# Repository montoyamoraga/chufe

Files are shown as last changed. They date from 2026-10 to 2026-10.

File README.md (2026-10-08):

# chufe

## About

chufe is an open source hardware Eurorack power supply by [piruetas](https://piruetas.xyz). It takes 12 V DC from a barrel jack, with reverse polarity protection, and outputs ±12V (from a 20 W isolated DC-DC converter) and +5V (from an L7805 linear regulator) on a 16-pin Eurorack power header and a 4-pin Molex KK-396 connector, with an LED for each rail. It is designed to feed a power bus such as [chufebu](https://github.com/piruetasxyz/chufebu). The design is made in KiCad 10 with KiCad's standard libraries plus one third-party part, included in `terceros/`. Hardware is licensed under CERN-OHL-P-2.0 and documentation under CC-BY-SA-4.0 (see [LICENSE.md](./LICENSE.md)). Documentation, schematic, board render and bill of materials (in Spanish): <https://piruetas.xyz/chufe/>.

## Acerca de

Fuente de alimentación eurorack de [piruetas](https://piruetas.xyz), hecha en KiCad y publicada como hardware de código abierto.

Documentación, esquemático, placa y Bill of materials: <https://piruetas.xyz/chufe/>.

## Características

- Entrada de 12 V DC por jack, con protección contra polaridad inversa.
- Salidas de +12V y -12V desde un convertidor DC-DC aislado de 20 W (URA2412YMD-20WR3).
- Salida de +5V desde un regulador lineal L7805, alimentado desde +12V.
- Un header de alimentación Eurorack de 16 pines (2x08) y un conector Molex KK-396 de 4 pines: -12V, GND, +5V y +12V.
- 4 LEDs indicadores: entrada, -12V, +12V y +5V.
- Placa de 50 × 65 mm, 2 capas, con 4 agujeros de montaje M3.
- Hecha para alimentar un bus como [chufebu](https://github.com/piruetasxyz/chufebu).

## Pines y manual de uso

Los pines del header de 16 pines y del conector KK-396, cómo conectar chufe y las advertencias están en el [manual de uso](https://piruetas.xyz/chufe/#manual-de-uso).

## Revisiones

- `v0.1 rev-a`: octubre 2026, todavía sin probar.

## Estructura del repositorio

- [hardware/chufe-v-0-rev-a](./hardware/chufe-v-0-rev-a): proyecto de KiCad (esquemático y placa), los archivos fuente del diseño.
- [hardware/chufe-v-0-rev-a-fab](./hardware/chufe-v-0-rev-a-fab): gerbers y archivos de taladrado para fabricar la placa.
- [hardware/chufe-v-0-rev-a-pcba](./hardware/chufe-v-0-rev-a-pcba): lista de componentes y archivo de posiciones para armado en JLCPCB.
- [terceros](./terceros): símbolo, huella y modelos 3D del convertidor URA2412YMD-20WR3, de la biblioteca de EasyEDA / LCSC / JLCPCB. Van en el repositorio para que el proyecto de KiCad se abra sin instalar bibliotecas adicionales.
- [docs](./docs): documentación, publicada en <https://piruetas.xyz/chufe/>. Las capturas del esquemático y de la placa, y la tabla de Bill of materials, las genera [kicad-retrata](https://github.com/piruetasxyz/kicad-retrata) en cada push (ver [kicad-retrata.yml](./kicad-retrata.yml)).
- [LICENSES](./LICENSES): textos completos de las licencias.

## Fabricación

piruetas vende chufe armado y probado.

Como es hardware de código abierto, los archivos fuente de KiCad, los archivos de fabricación de [hardware/chufe-v-0-rev-a-fab](./hardware/chufe-v-0-rev-a-fab), los de armado de [hardware/chufe-v-0-rev-a-pcba](./hardware/chufe-v-0-rev-a-pcba) y la [Bill of materials](https://piruetas.xyz/chufe/#bill-of-materials-v01-rev-a) están publicados para que cualquiera pueda estudiar, modificar y fabricar el diseño. piruetas no da soporte para unidades fabricadas o armadas por terceros.

## Créditos

- Aarón Montoya-Moraga: investigación, esquemático, PCB, fabricación y documentación.
- Matías Serrano: revisor experto de esquemáticos y PCBs.

## Licencia

chufe es (c) 2026 piruetas SpA / Aarón Montoya-Moraga.

- Hardware (`hardware/`): [CERN-OHL-P-2.0](./LICENSES/CERN-OHL-P-2.0.txt).
- Documentación (`docs/`): [CC-BY-SA-4.0](./LICENSES/CC-BY-SA-4.0.txt).
- El nombre, logo y marca de piruetas no están cubiertos por estas licencias: ver [LicenseRef-piruetas-branding](./LICENSES/LicenseRef-piruetas-branding.txt).
- Componentes de terceros (`terceros/`): el símbolo, la huella y los modelos 3D del convertidor DC-DC URA2412YMD-20WR3 ([LCSC C5369773](https://www.lcsc.com/product-detail/C5369773.html)) vienen de la biblioteca de EasyEDA / LCSC / JLCPCB, convertidos a KiCad con [easyeda2kicad](https://github.com/uPesy/easyeda2kicad.py). No son obra de piruetas ni están cubiertos por estas licencias: ver [LicenseRef-easyeda](./LICENSES/LicenseRef-easyeda.txt).

Ver [LICENSE.md](./LICENSE.md) para los detalles. El repositorio sigue la especificación [REUSE](https://reuse.software/).

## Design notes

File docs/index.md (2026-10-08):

# chufe

Fuente de alimentación eurorack: recibe 12 V DC por un jack y entrega ±12V y +5V en un header de 16 pines (2x08) y en un conector Molex KK-396 de 4 pines.

## Revisiones

- `v0.1 rev-a`: octubre 2026, todavía sin probar.

## Cómo funciona

1. La entrada llega por el jack DC (J3) y pasa por un MOSFET canal P (Q1) que protege contra polaridad inversa. El zener D1 limita el voltaje gate-source de Q1.
2. El convertidor DC-DC URA2412YMD-20WR3 (U1) genera +12V y -12V.
3. El regulador lineal L7805 (U2) genera +5V a partir de +12V.
4. Las tres líneas salen al header de 16 pines (J1) y al conector Molex KK-396 (J2).
5. Cuatro LEDs indican la presencia de cada voltaje: entrada (D2), -12V (D3), +12V (D4) y +5V (D5).

## Manual de uso

### Qué necesitas

- Una fuente de 12 V DC con plug de centro positivo, para el jack de entrada.
- Un bus de alimentación eurorack, por ejemplo [chufebu](https://piruetas.xyz/chufebu/), y un cable plano de 16 pines (16-16), o un cable con conector Molex KK-396 de 4 pines.
- Opcional: 4 tornillos M3 y separadores para montar la placa.

### Conexión

1. Con la fuente de 12 V **desenchufada**, conecta chufe al bus con el cable plano o con el cable Molex.
2. Si usas el cable plano, orienta la **franja roja hacia -12V** (pin 1, marcado en el serigrafiado del header).
3. Revisa las conexiones y después enchufa la fuente de 12 V al jack.
4. Revisa que los cuatro LEDs estén encendidos: el de la entrada, junto al jack, y los de `-12`, `12` y `5`, marcados en el serigrafiado.

### Pines

Header de 16 pines (según el estándar Eurorack de Doepfer):

| Pines | Señal |
| --- | --- |
| 1, 2 | -12V |
| 3 a 8 | GND |
| 9, 10 | +12V |
| 11, 12 | +5V |
| 13, 14 | CV (sin conectar) |
| 15, 16 | GATE (sin conectar) |

Conector Molex KK-396 de 4 pines:

| Pin | Señal |
| --- | --- |
| 1 | -12V |
| 2 | GND |
| 3 | +5V |
| 4 | +12V |

### Advertencias

- Un cable plano conectado al revés puede dañar el bus, los módulos o chufe. El header tiene carcasa con muesca de polarización, pero revisa siempre la franja roja.
- Conecta y desconecta cables solamente con la fuente de 12 V desenchufada.
- chufe tiene protección contra polaridad inversa en la entrada, pero no tiene fusibles.
- El convertidor entrega 20 W en total entre +12V y -12V. La corriente de +5V sale de la línea de +12V, así que también cuenta en ese total. Suma el consumo de tus módulos en cada línea y no superes lo que entrega chufe.
- El L7805 disipa como calor la diferencia entre 12V y 5V: mientras más corriente de +5V uses, más se calienta.

## Esquemático y placa (v0.1 rev-a)

Generados automáticamente por GitHub Actions a partir de `hardware/chufe-v-0-rev-a/chufe-v-0-rev-a.kicad_sch` y `.kicad_pcb` en cada push que los modifica.

Esquemático de chufe v0.1 rev-a

Placa de chufe v0.1 rev-a

Render 3D de la placa:

<video src="./videos/chufe-placa-3d-giro.mp4" autoplay loop muted playsinline width="540">Render 3D de la placa de chufe v0.1 rev-a.</video>

## Bill of materials (v0.1 rev-a)

Generado a partir de `hardware/chufe-v-0-rev-a/chufe-v-0-rev-a.kicad_sch`.

<!-- BOM_TABLE_START -->

| Referencias | Cantidad | Valor | Huella | Descripción |
| --- | --- | --- | --- | --- |
| C1, C2 | 2 | 100n | Capacitor_SMD:C_0805_2012Metric | Capacitor cerámico |
| C3 | 1 | 22u | Capacitor_SMD:CP_Elec_4x5.4 | Capacitor electrolítico |
| D1 | 1 | BZT52C5V6 | Diode_SMD:D_SOD-123 | Diodo zener, limita el voltaje gate-source de Q1 |
| D2, D3, D4, D5 | 4 | LED | LED_THT:LED_D3.0mm | LED indicador de 3 mm, THT |
| J1 | 1 | Conn_02x08_Odd_Even | Connector_IDC:IDC-Header_2x08_P2.54mm_Vertical | Header de alimentación Eurorack (16 pines): box header 2x08, 2.54 mm, vertical, THT, con carcasa y muesca de polarización ([Thonk](https://www.thonk.co.uk/shop/16pin-power-headers-shrouded/)) |
| J2 | 1 | Conn_01x04_Pin | Connector_Molex:Molex_KK-396_5273-04A_1x04_P3.96mm_Vertical | Conector de alimentación (4 pines): Molex KK-396 5273-04A, 1x04, 3.96 mm, vertical, THT |
| J3 | 1 | Barrel_Jack_Switch | Connector_BarrelJack:BarrelJack_Horizontal | Jack DC (barrel jack) de entrada, horizontal, THT |
| Q1 | 1 | AO3401A | Package_TO_SOT_SMD:SOT-23 | MOSFET canal P, protección contra polaridad inversa en la entrada |
| R1 | 1 | 22k | Resistor_SMD:R_0805_2012Metric | Resistencia |
| R2, R3, R4 | 3 | 10k | Resistor_SMD:R_0805_2012Metric | Resistencia |
| R5 | 1 | 2k2 | Resistor_SMD:R_0805_2012Metric | Resistencia |
| U1 | 1 | URA2412YMD-20WR3_C5369773 | easyeda2kicad:PWRM-TH_YLPTEC_VRBXXXXYMD-20WR3 | Convertidor DC-DC aislado ±12V: URA2412YMD-20WR3, 20 W, THT ([LCSC C5369773](https://www.lcsc.com/product-detail/C5369773.html)) |
| U2 | 1 | L7805 | Package_TO_SOT_SMD:TO-252-2 | Regulador de voltaje lineal +5V |

19 componentes en total.

<!-- BOM_TABLE_END -->

### Placa (PCB)

Fabricar con los gerbers y archivos de taladrado de [`hardware/chufe-v-0-rev-a-fab`](https://github.com/piruetasxyz/chufe/tree/main/hardware/chufe-v-0-rev-a-fab).

| Especificación | Valor |
| --- | --- |
| Capas | 2 |
| Tamaño | 50 × 65 mm |
| Grosor | 1.6 mm |
| Cobre | 35 µm (1 oz) |
| Acabado superficial | HASL sin plomo (LeadFree HASL) |

### Armado (PCBA)

Para armado en JLCPCB, la lista de componentes con números de parte de LCSC y el archivo de posiciones están en [`hardware/chufe-v-0-rev-a-pcba`](https://github.com/piruetasxyz/chufe/tree/main/hardware/chufe-v-0-rev-a-pcba). Los LEDs (D2 a D5) y los conectores (J1, J2 y J3) no están en esa lista y se sueldan a mano.

## Créditos

- Aarón Montoya-Moraga: investigación, esquemático, PCB, fabricación y documentación.
- Matías Serrano: revisor experto de esquemáticos y PCBs.

## Licencia

El hardware está bajo CERN-OHL-P-2.0 y esta documentación bajo CC-BY-SA-4.0. El símbolo, la huella y los modelos 3D del convertidor URA2412YMD-20WR3, en `terceros/`, son de EasyEDA / LCSC / JLCPCB y no están cubiertos por estas licencias. Ver [LICENSE.md](https://github.com/piruetasxyz/chufe/blob/main/LICENSE.md).

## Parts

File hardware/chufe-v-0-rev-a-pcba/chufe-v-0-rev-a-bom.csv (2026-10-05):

Comment | Designator | Footprint | LCSC Part #
100n | C1,C2 | Capacitor_SMD:C_0805_2012Metric | C49678
22u | C3 | Capacitor_SMD:CP_Elec_4x5.4 | C72502
BZT52C5V6 | D1 | Diode_SMD:D_SOD-123 | C19077402
AO3401A | Q1 | Package_TO_SOT_SMD:SOT-23 | C15127
22k | R1 | Resistor_SMD:R_0805_2012Metric | C31850
10k | R2,R3,R4 | Resistor_SMD:R_0805_2012Metric | C17414
2k2 | R5 | Resistor_SMD:R_0805_2012Metric | C17520
URA2412YMD-20WR3_C5369773 | U1 | easyeda2kicad:PWRM-TH_YLPTEC_VRBXXXXYMD-20WR3 | C5369773
L7805 | U2 | Package_TO_SOT_SMD:TO-252-2 | C19626525

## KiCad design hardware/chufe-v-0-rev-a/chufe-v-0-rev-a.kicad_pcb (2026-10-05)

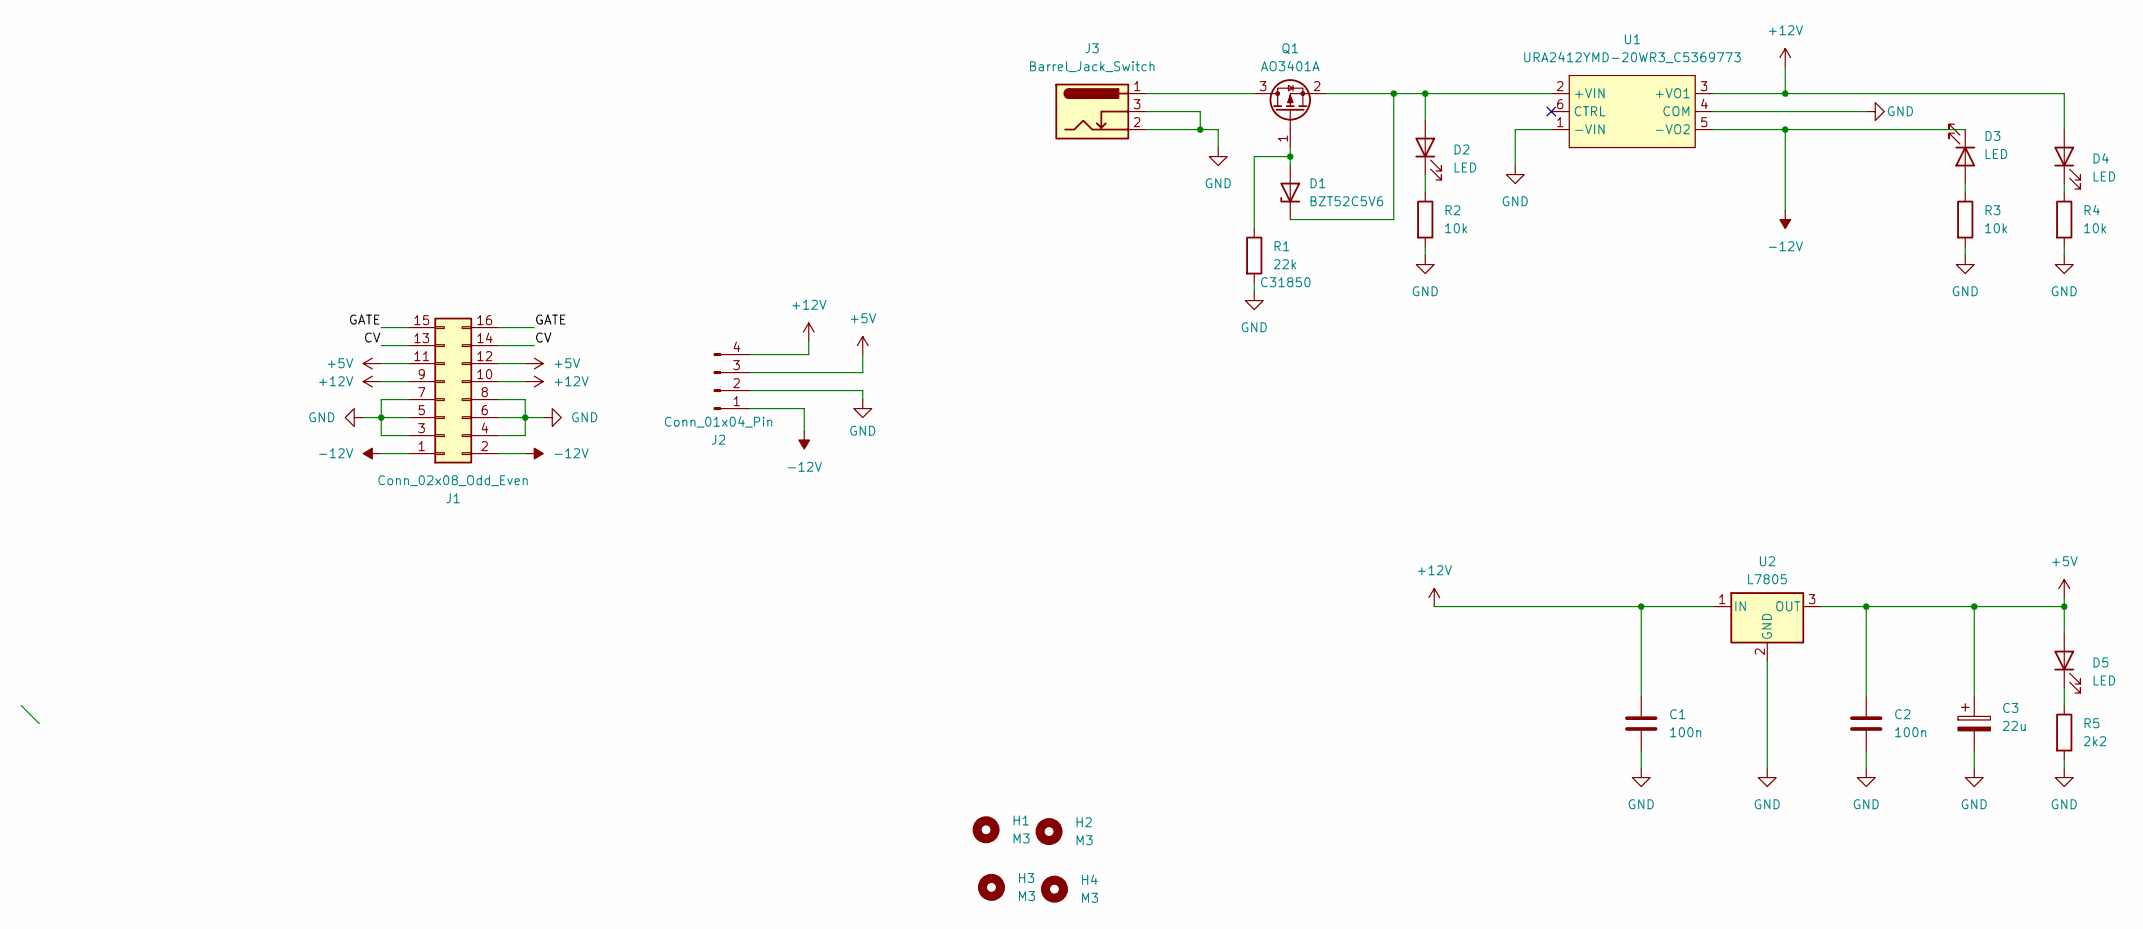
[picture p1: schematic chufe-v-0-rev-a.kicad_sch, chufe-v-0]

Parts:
C1, C2: 100n; C_0805_2012Metric; LCSC C49678
C3: 22u; CP_Elec_4x5.4; LCSC C72502
D1: BZT52C5V6; D_SOD-123; LCSC C19077402
D2, D3, D4, D5: LED; LED_D3.0mm
H1, H2, H3, H4: M3; MountingHole_3.2mm_M3
J1: Conn_02x08_Odd_Even; IDC-Header_2x08_P2.54mm_Vertical
J2: Conn_01x04_Pin; Molex_KK-396_5273-04A_1x04_P3.96mm_Vertical
J3: Barrel_Jack_Switch; BarrelJack_Horizontal
Q1: AO3401A; SOT-23; LCSC C15127
R1: 22k; R_0805_2012Metric; LCSC C31850
R2, R3, R4: 10k; R_0805_2012Metric; LCSC C17414
R5: 2k2; R_0805_2012Metric; LCSC C17520
U1: URA2412YMD-20WR3_C5369773; PWRM-TH_YLPTEC_VRBXXXXYMD-20WR3; MPN URA2412YMD-20WR3; LCSC Part C5369773
U2: L7805; TO-252-2; LCSC C19626525

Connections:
+5V: C2.1, C3.1, D5.2 (A), J1.11, J1.12, J2.3, U2.3 (OUT)
+12V: C1.1, D4.2 (A), J1.9, J1.10, J2.4, U1.3 (+VO1), U2.1 (IN)
-12V: D3.1 (K), J1.1, J1.2, J2.1, U1.5 (-VO2)
/CV: J1.13, J1.14
/GATE: J1.15, J1.16
GND: C1.2, C2.2, C3.2, J1.3, J1.4, J1.5, J1.6, J1.7, J1.8, J2.2, J3.2, J3.3, R1.2, R2.2, R3.2, R4.2, R5.2, U1.1 (-VIN), U1.4 (COM), U2.2 (GND)
unnamed: D1.2 (A), Q1.1 (G), R1.1
unnamed: D1.1 (K), D2.2 (A), Q1.2 (S), U1.2 (+VIN)
unnamed: D2.1 (K), R2.1
unnamed: D3.2 (A), R3.1
unnamed: D4.1 (K), R4.1
unnamed: D5.1 (K), R5.1
unnamed: J3.1, Q1.3 (D)

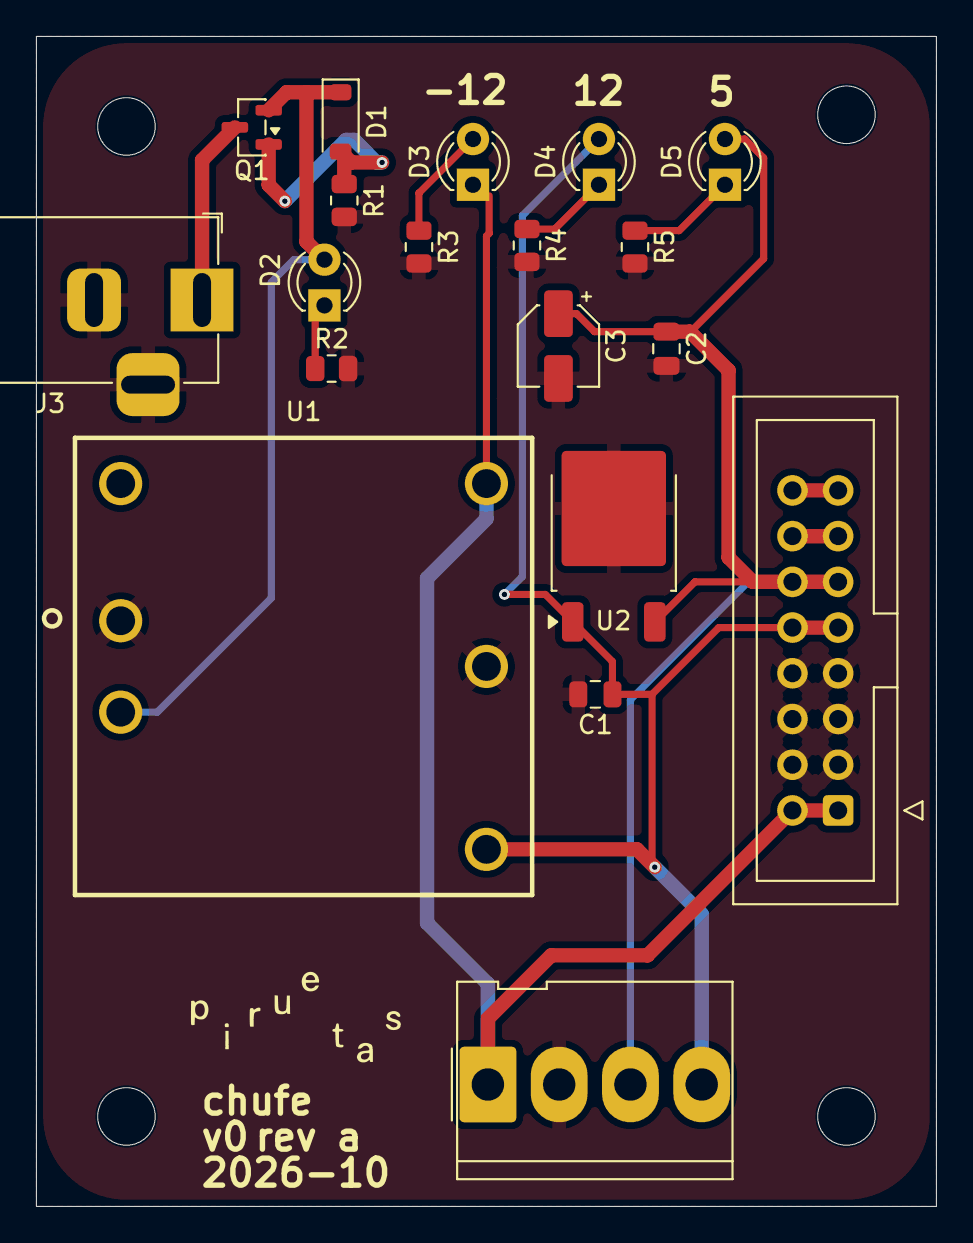
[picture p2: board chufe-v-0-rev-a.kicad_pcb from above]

Board: 2 copper layers, 50.0 x 65.0 mm, 23 parts (0 on the bottom side), 13 nets.

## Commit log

2026-10-05 agregar requirements.txt para python
2026-10-05 agregar hardware/ desde repo antiguo popusintes-esquematicos-placas
    [chufe-v-0-rev-a-B_Cu.gbr, chufe-v-0-rev-a-B_Mask.gbr, chufe-v-0-rev-a-B_Silkscreen.gbr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]
2026-10-05 agregar mas licencias sobre partes de terceros easyeda2kicad
    [chufe-v-0-rev-a.kicad_pcb]
2026-10-05 Actualizar capturas y BOM de esquemáticos y placas [skip ci]
